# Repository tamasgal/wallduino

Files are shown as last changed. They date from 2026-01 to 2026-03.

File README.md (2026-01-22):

# WallDuino

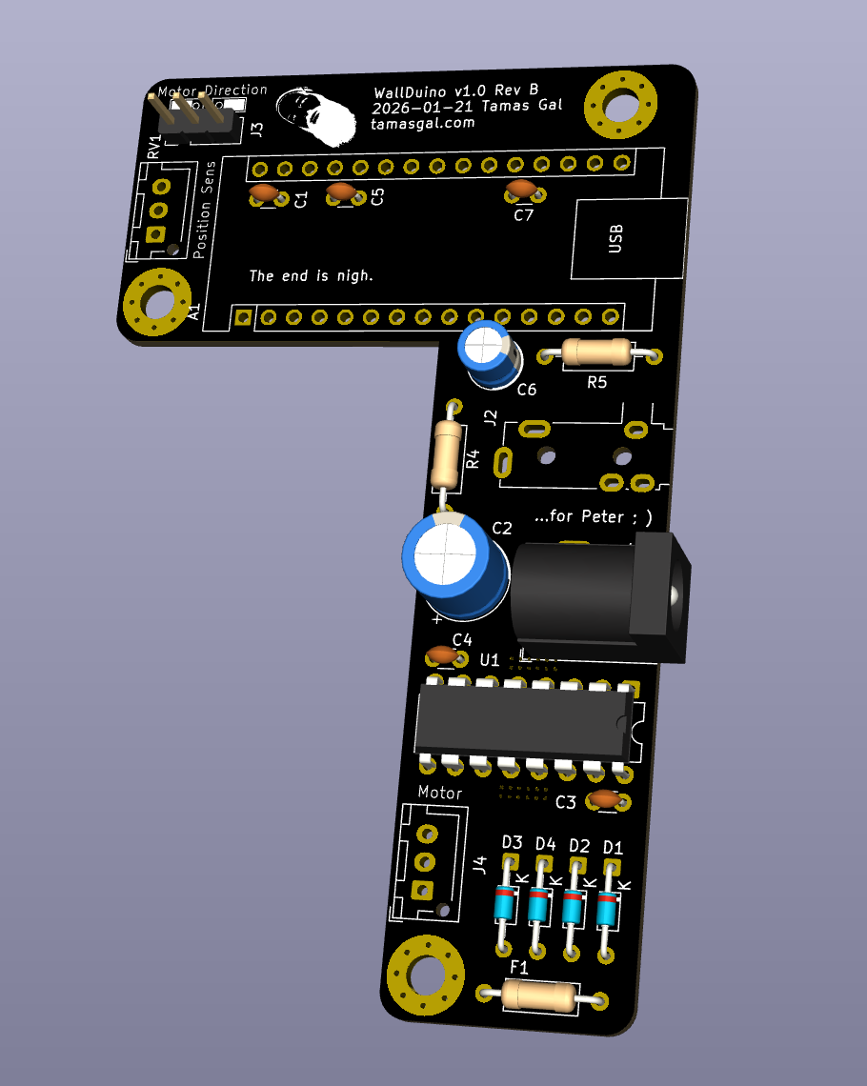
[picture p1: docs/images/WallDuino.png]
WallDuino


Drop-in replacement board for the WallWizard remote-controlled TV wall mount
including PCB, DIY veroboard (stripboard) layouts and an open source firmware
for Arduino compatible microcontrollers.

Manual: [`WallDuino_Manual.pdf`](https://github.com/tamasgal/wallduino/blob/main/docs/WallDuino_Manual.pdf)

## Firmware

Board: Arduino Nano compatible
Dependency: [Arduino-IRRemote v4.5](https://github.com/Arduino-IRremote/Arduino-IRremote)
Code: `firmware/WallDuino`

### Changelog

#### v1.1 - 2026-01-22

- Persistent presets after reboot
- Home button support to "go home"

#### v1.0 - 2026-01-09

Initial release

## PCB

### v1.0 (Rev A) 2026-01-08

First release.

### v1.0 (Rev B) 2026-01-21

- Heat sinking of the L293D improved significantly
- R1, R2 and R3 removed
- Added an additional capacitor to smooth out the position sensor signal from the potentiometer

## DIY Veroboard

The veroboard (stripboard) is Rev A and has a different Arduino pinout, so make sure
to adjust the firmware code.

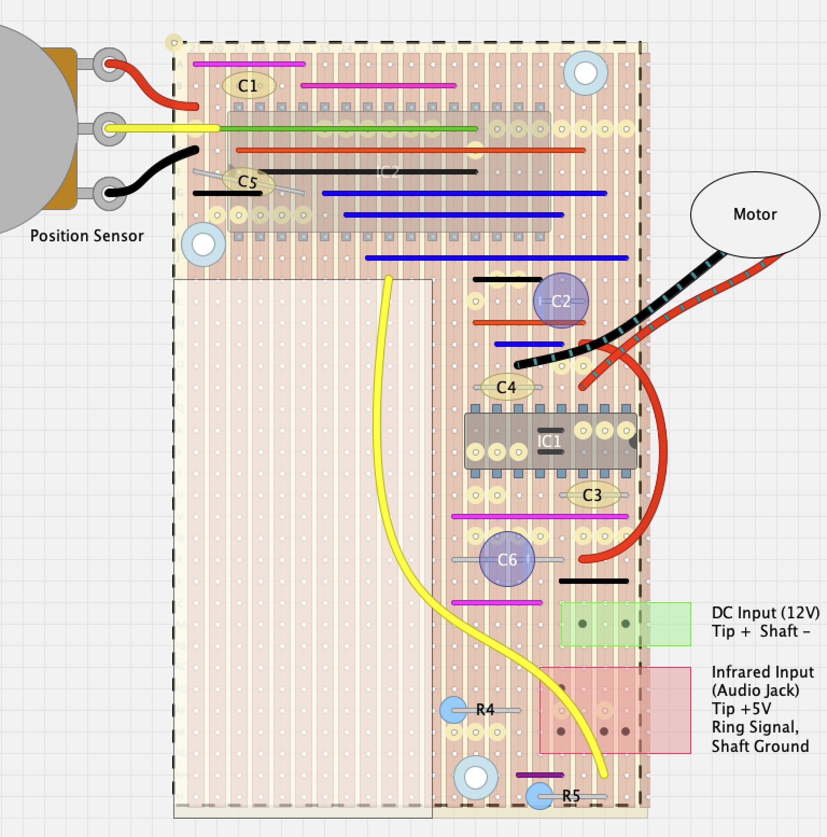
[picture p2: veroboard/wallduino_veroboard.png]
WallDuino


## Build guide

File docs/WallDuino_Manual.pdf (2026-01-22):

# WallDuino

## Open Source Ersatzboard für motorisierte WallWizard TV-Wandhalterungen

### Open-source replacement board for Motorized WallWizard TV Wall Mounts

### Tamas Gal - https://www.tamasgal.com

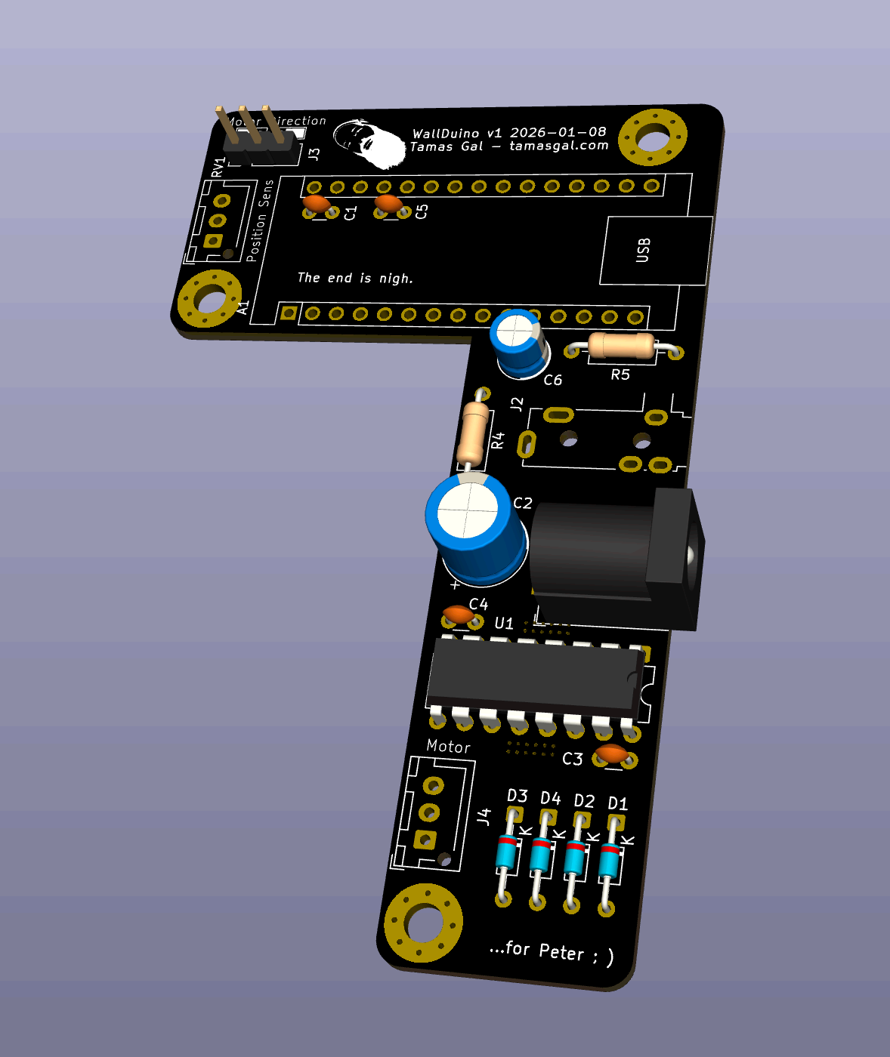
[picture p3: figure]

Bedienungsanleitung / User Manual

Custom DIY Mainboard Replacement

# Bedienungsanleitung

## Einleitung

Dieses Handbuch beschreibt die Verwendung des WallDuino, einer selbstgebauten DIY-Platine, die als Ersatz für die originale WallWizard-Hauptplatine (P/N: 417-S3-001-00 CLO SYSTEMS 2010.12.25) dient.

Der WallDuino ist vollständig kompatibel mit dem originalen Layout und der originalen Fernbedienung des WallWizard-Systems. Die Platine wurde entwickelt, um alle Funktionen der Originalplatine zu ersetzen und bietet zusätzlich die Möglichkeit zur Anpassung der Firmware.

Open Source Projekt: Der WallDuino ist ein Open-Source-Projekt. Die Firmware und alle Designdateien finden Sie im offiziellen Git-Repository: https://github.com/tamasgal/wallduino

## Übersicht

Der WallDuino steuert eine motorisierte TV-Wandhalterung, die es Ihnen ermöglicht, Ihren Fernseher horizontal nach links und rechts zu bewegen. Die Steuerung erfolgt bequem über die kompatible Fernbedienung.

## Fernbedienung

Die Fernbedienung verfügt über folgende Tasten:

Taste | Funktion
◄ Links | Bewegt die Halterung nach links
- Rechts | Bewegt die Halterung nach rechts
■ Stop | Stoppt die Bewegung sofort
Preset 1 | Positionsspeicher 1
Preset 2 | Positionsspeicher 2

## Bedienung

Grundlegende Bewegung
Links/Rechts bewegen:
- Drücken Sie die Taste ◄ (Links) oder ► (Rechts)
- Die Halterung bewegt sich in die gewählte Richtung

- Die Bewegung stoppt automatisch bei Erreichen der Endposition Bewegung stoppen:
- Drücken Sie die ■ (Stop)-Taste, um die Bewegung jederzeit zu unterbrechen

Preset-Positionen
Die Preset-Tasten ermöglichen es Ihnen, zwei Lieblingspositionen zu speichern und schnell anzufahren.
Position anfahren:
- Drücken Sie einmal auf Preset 1 oder Preset 2
- Die Halterung fährt automatisch zur gespeicherten Position
Position speichern:
- Bewegen Sie die Halterung zur gewünschten Position
- Drücken Sie dreimal schnell hintereinander auf Preset 1 oder Preset 2
- Die aktuelle Position ist nun gespeichert

Hinweis: Die Preset-Positionen bleiben auch nach dem Ausschalten gespeichert.

## Sicherheitshinweise

- Achten Sie darauf, dass sich keine Gegenstände oder Personen im Bewegungsbereich befinden
- Verwenden Sie die Stop-Taste bei unerwarteten Hindernissen
- Prüfen Sie regelmäßig die sichere Montage der Halterung
- Bei Fehlfunktionen trennen Sie das Gerät vom Strom und kontaktieren Sie den Kundendienst

## Firmware-Anpassung

Ein besonderer Vorteil des WallDuino ist die Möglichkeit, die Firmware nach eigenen Wünschen anzupassen. Dies ermöglicht es Ihnen:
Zusätzliche Fernbedienungsbefehle hinzufügen:
- Ungenutzte Tasten bestehender TV-Fernbedienungen verwenden
- Beliebige andere Fernbedienungen einlernen
- Eigene Befehle und Funktionen programmieren Anpassungsmöglichkeiten:
- IR-Codes neuer Fernbedienungen hinzufügen
- Bewegungsgeschwindigkeit anpassen
- Zusätzliche Preset-Positionen definieren

- Spezielle Bewegungsabläufe programmieren

Die vollständige Firmware sowie Anleitungen zur Anpassung finden Sie im offiziellen Repository:
https://github.com/tamasgal/wallduino

# User Manual

## Introduction

This manual describes the use of the WallDuino, a custom DIY board that serves as a replacement for the original WallWizard mainboard (P/N: 417-S3-001-00 CLO SYSTEMS 2010.12.25).

The WallDuino is fully compatible with the original layout and the original remote control of the WallWizard system. The board was designed to replace all functions of the original board and additionally offers the possibility to customize the firmware.

Open Source Project: The WallDuino is an open source project. The firmware and all design files can be found in the official Git repository: https://github.com/tamasgal/wallduino

## Overview

The WallDuino controls a motorized TV wall mount that allows you to move your television horizontally to the left and right. Control is conveniently managed via the compatible remote control.

## Remote Control

The remote control features the following buttons:

Button | Function
◄ Left | Moves the mount to the left
- Right | Moves the mount to the right
■ Stop | Stops the movement immediately
Preset 1 | Position memory 1
Preset 2 | Position memory 2

## Operation

Basic Movement
Moving Left/Right:
- Press the ◄ (Left) or ► (Right) button
- The mount will move in the selected direction

- Movement stops automatically when reaching the end position Stopping Movement:
- Press the ■ (Stop) button to interrupt movement at any time

Preset Positions
The preset buttons allow you to save two favorite positions and navigate to them quickly.
Navigate to Position:
- Press Preset 1 or Preset 2 once
- The mount will automatically move to the saved position Save Position:
- Move the mount to the desired position
- Press Preset 1 or Preset 2 three times quickly in succession
- The current position is now saved

Note: Preset positions remain saved even after powering off.

## Safety Instructions

- Ensure no objects or persons are in the movement range
- Use the Stop button if unexpected obstacles appear
- Regularly check the secure mounting of the bracket
- In case of malfunction, disconnect the device from power and contact customer service

## Firmware Customization

A special advantage of the WallDuino is the ability to customize the firmware according to your own preferences. This allows you to:
Add Additional Remote Commands:
- Use unused buttons from existing TV remotes
- Learn any other remote controls
- Program custom commands and functions Customization Options:
- Add IR codes from new remote controls
- Adjust movement speed
- Define additional preset positions
- Program special movement sequences

The complete firmware and instructions for customization can be found in the official repository:
https://github.com/tamasgal/wallduino

# Anhang / Appendix

## PCB-Dokumentation / PCB Documentation

Die folgenden Seiten enthalten detaillierte technische Zeichnungen und Schaltpläne der WallDuino-Platine.

The following pages contain detailed technical drawings and schematics of the WallDuino board.

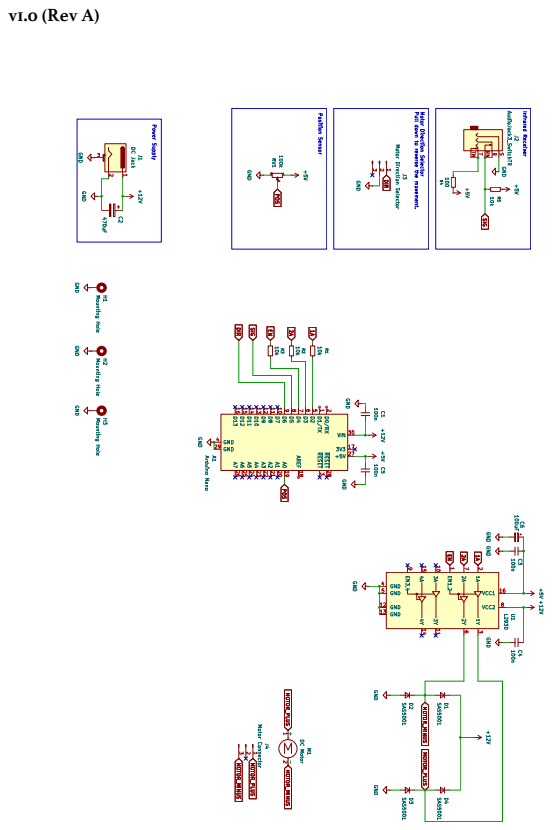
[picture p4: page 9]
v1.0 (Rev A)

## Vorderseite mit Beschriftung / Front Copper with Silkscreen

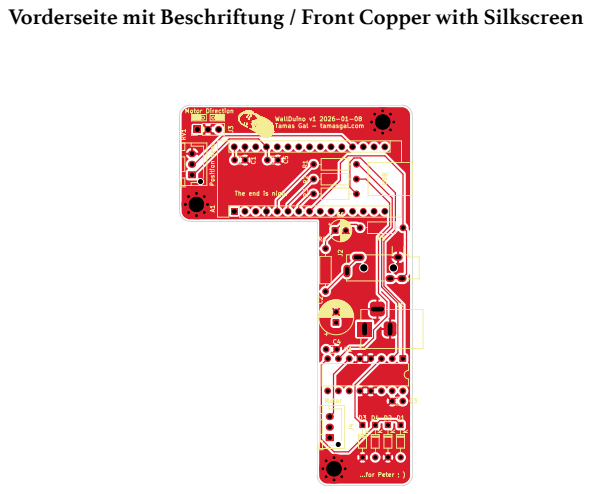
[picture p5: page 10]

## Vorderseite ohne Beschriftung / Front Copper without Silkscreen

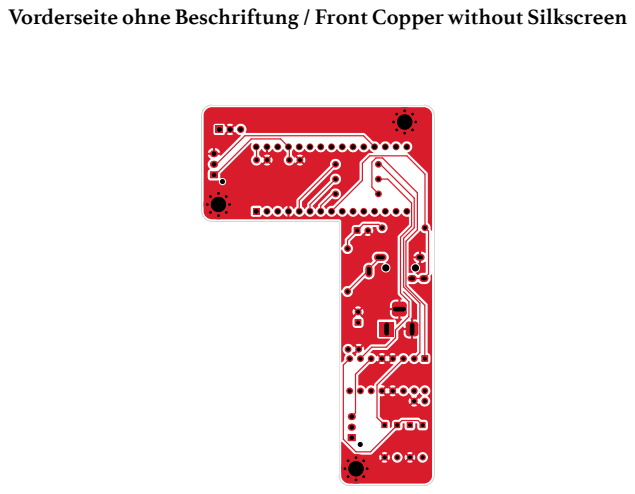
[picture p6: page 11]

## Rückseite mit Beschriftung / Back Copper with Silkscreen

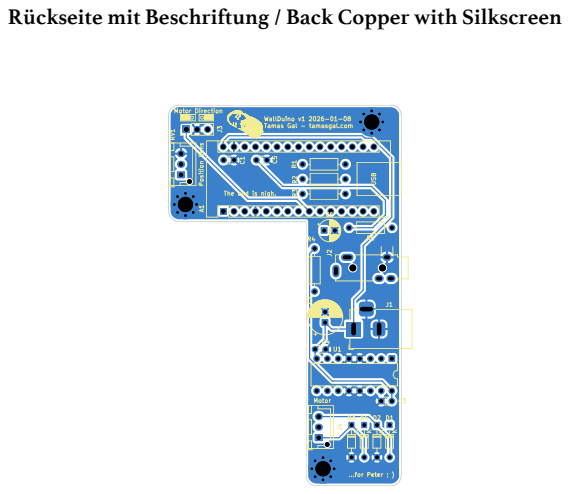
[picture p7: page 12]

## Rückseite ohne Beschriftung / Back Copper without Silkscreen

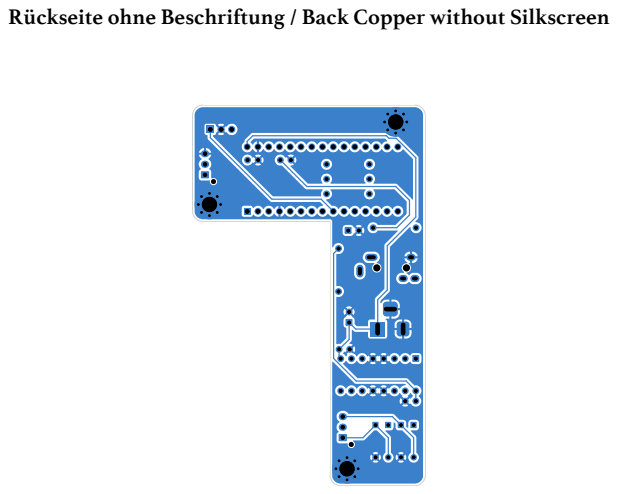
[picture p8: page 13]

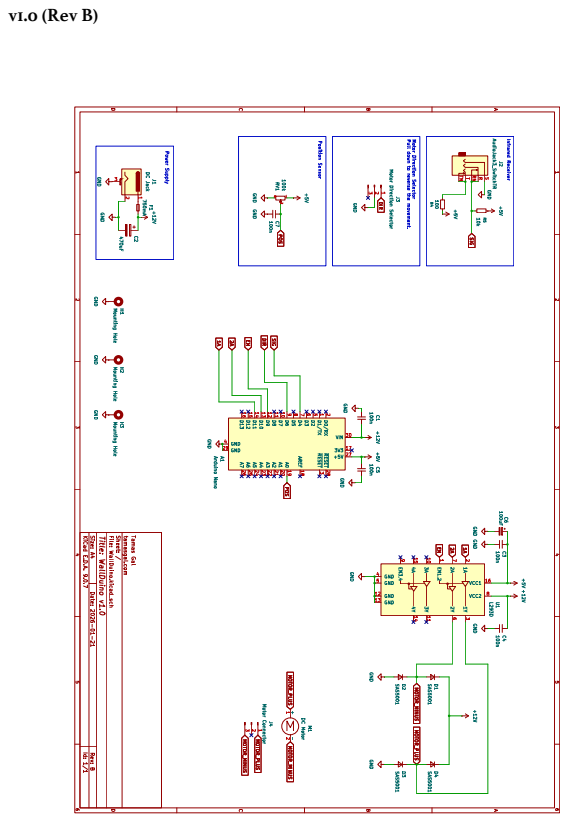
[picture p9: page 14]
v1.0 (Rev B)

## Vorderseite mit Beschriftung / Front Copper with Silkscreen

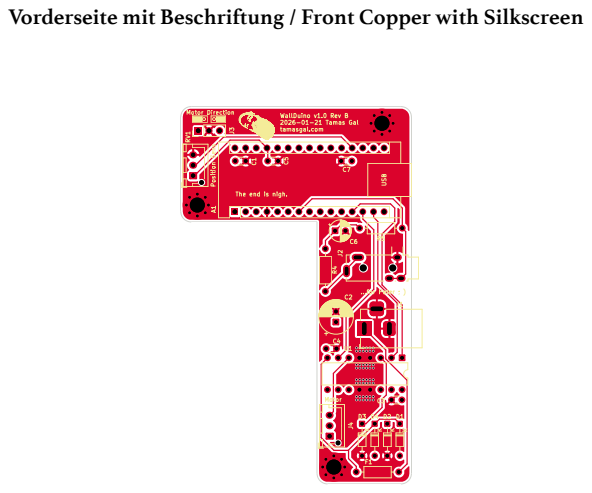
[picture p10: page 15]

## Vorderseite ohne Beschriftung / Front Copper without Silkscreen

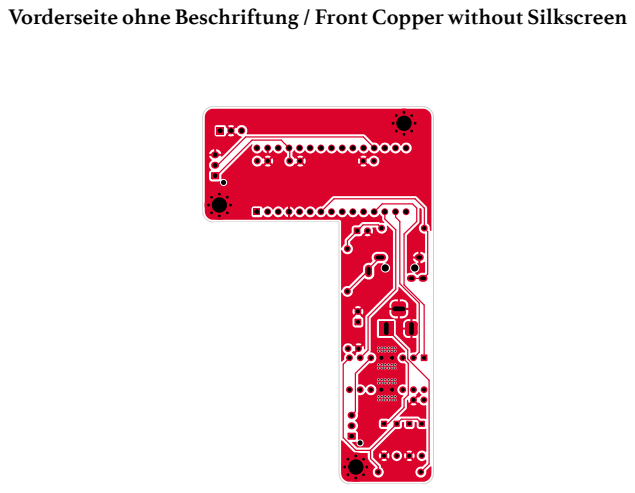
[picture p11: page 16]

## Rückseite mit Beschriftung / Back Copper with Silkscreen

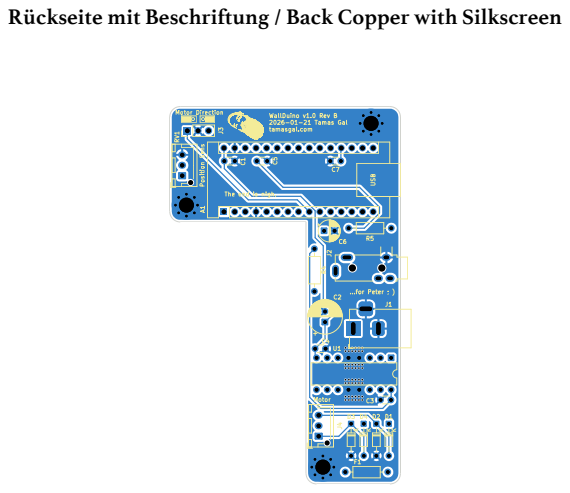
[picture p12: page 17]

## Rückseite ohne Beschriftung / Back Copper without Silkscreen

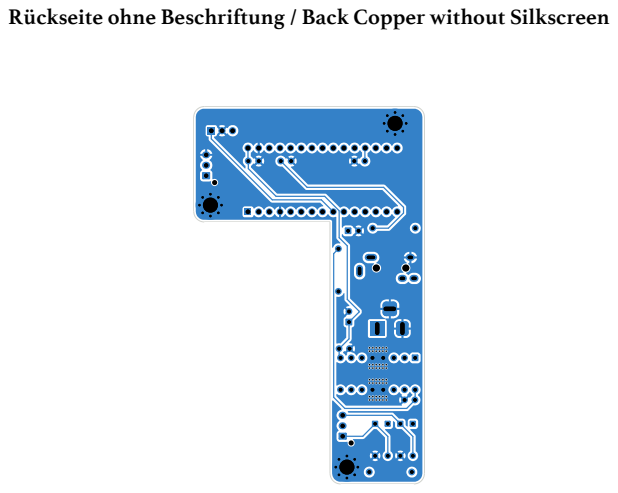
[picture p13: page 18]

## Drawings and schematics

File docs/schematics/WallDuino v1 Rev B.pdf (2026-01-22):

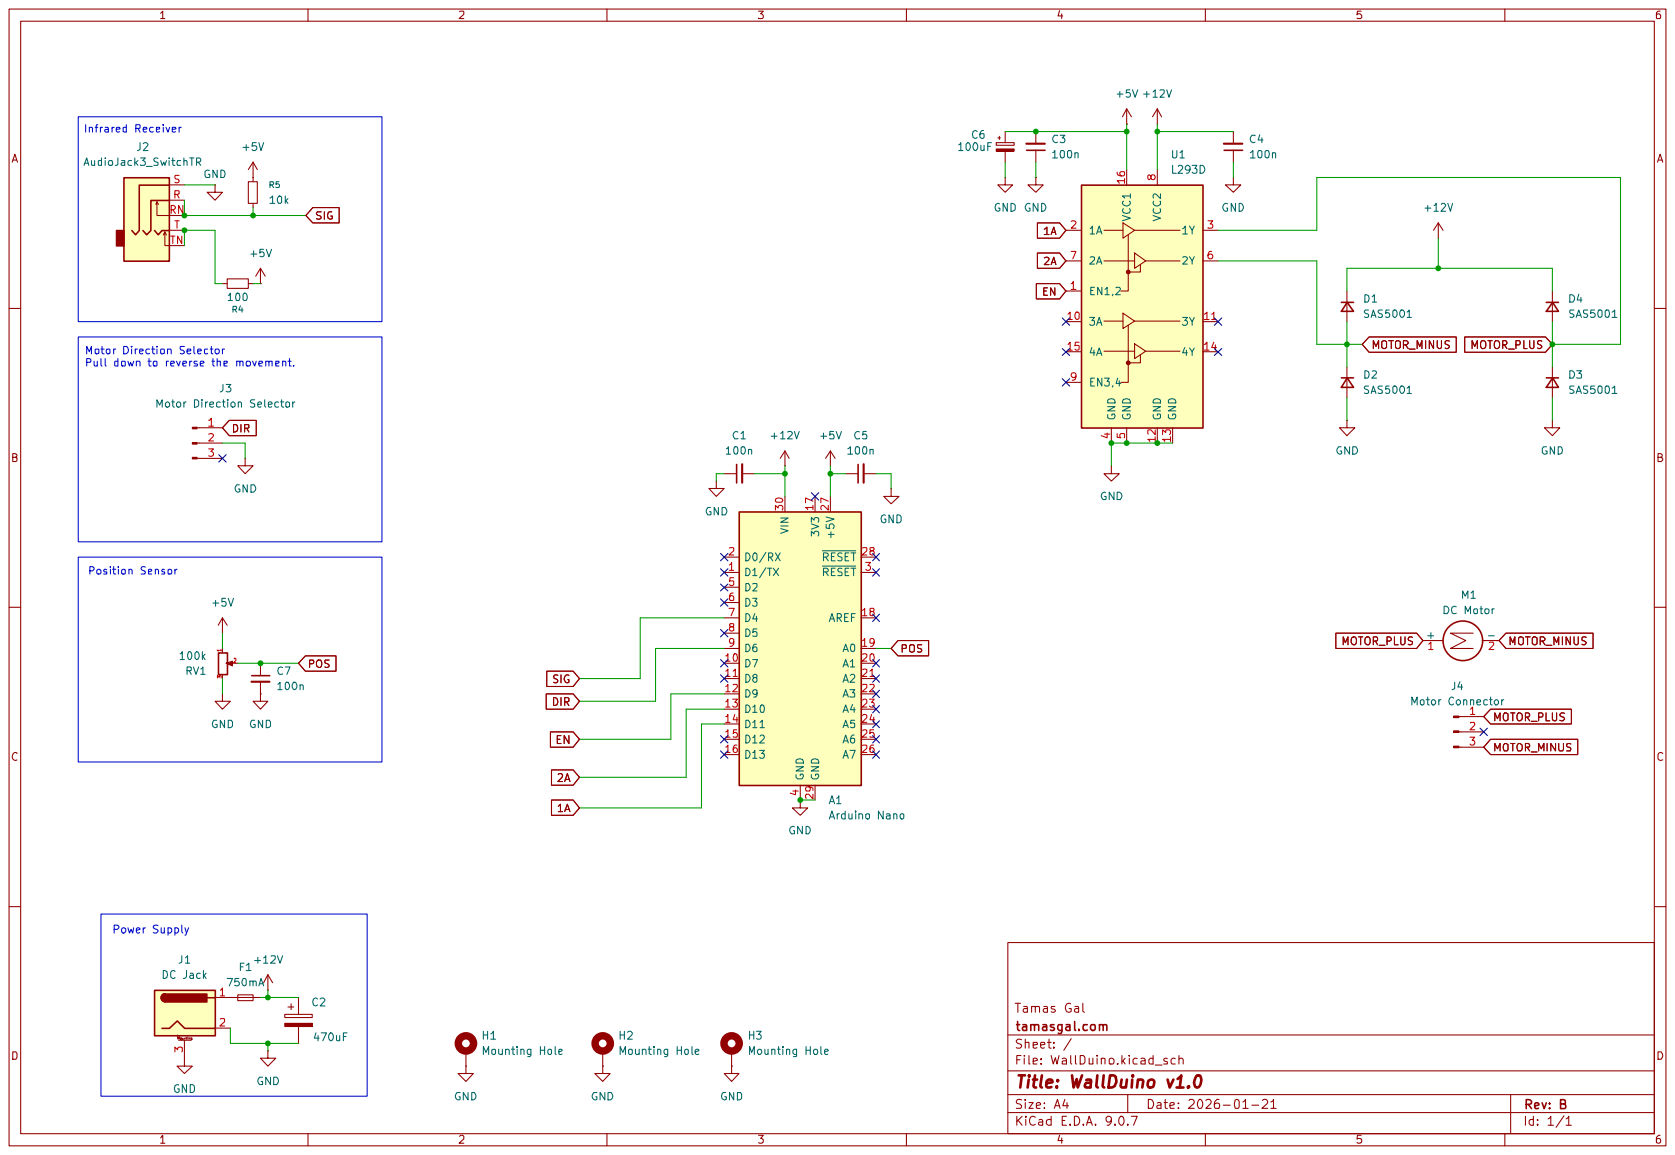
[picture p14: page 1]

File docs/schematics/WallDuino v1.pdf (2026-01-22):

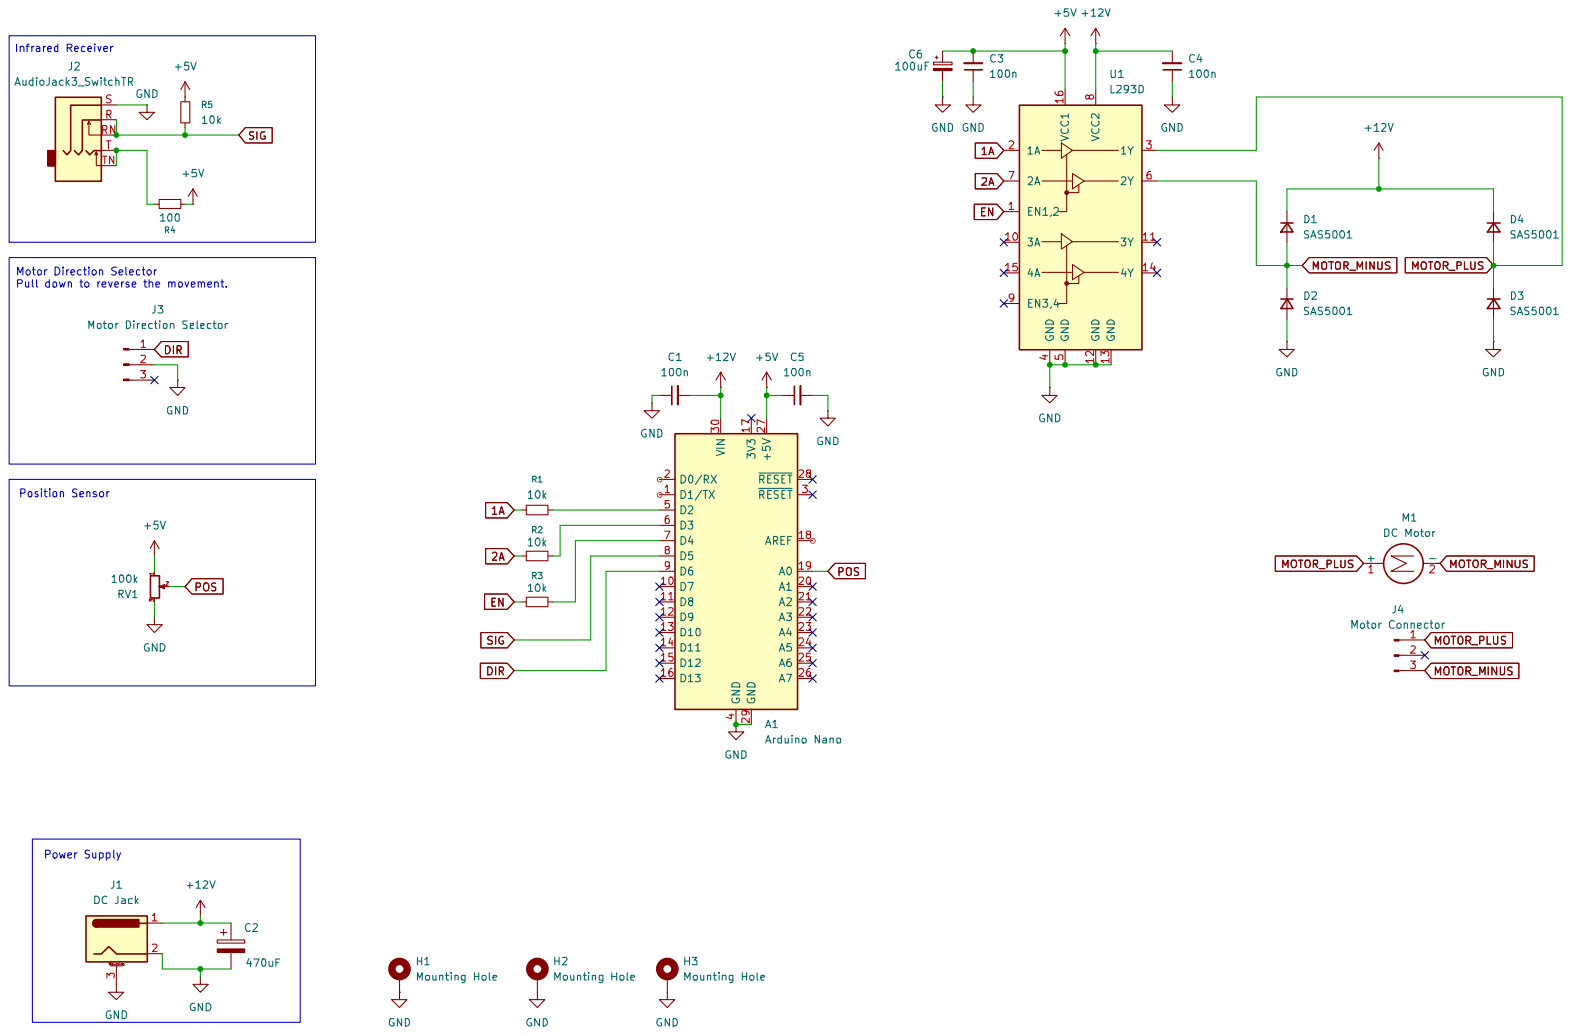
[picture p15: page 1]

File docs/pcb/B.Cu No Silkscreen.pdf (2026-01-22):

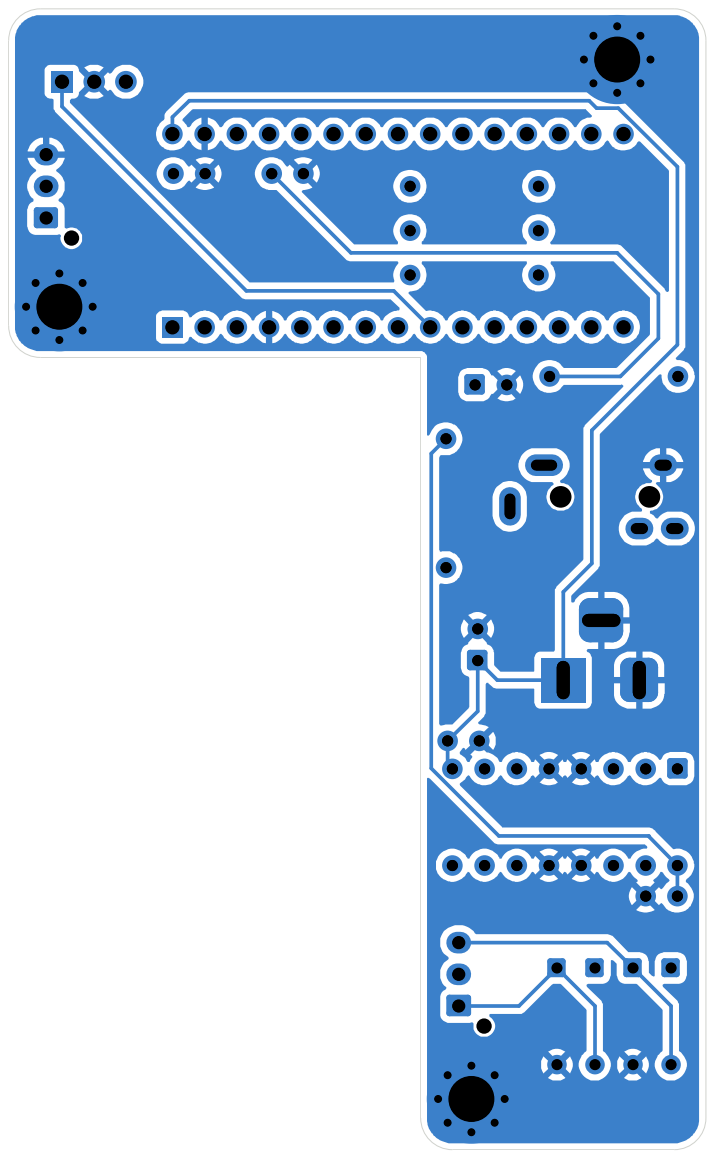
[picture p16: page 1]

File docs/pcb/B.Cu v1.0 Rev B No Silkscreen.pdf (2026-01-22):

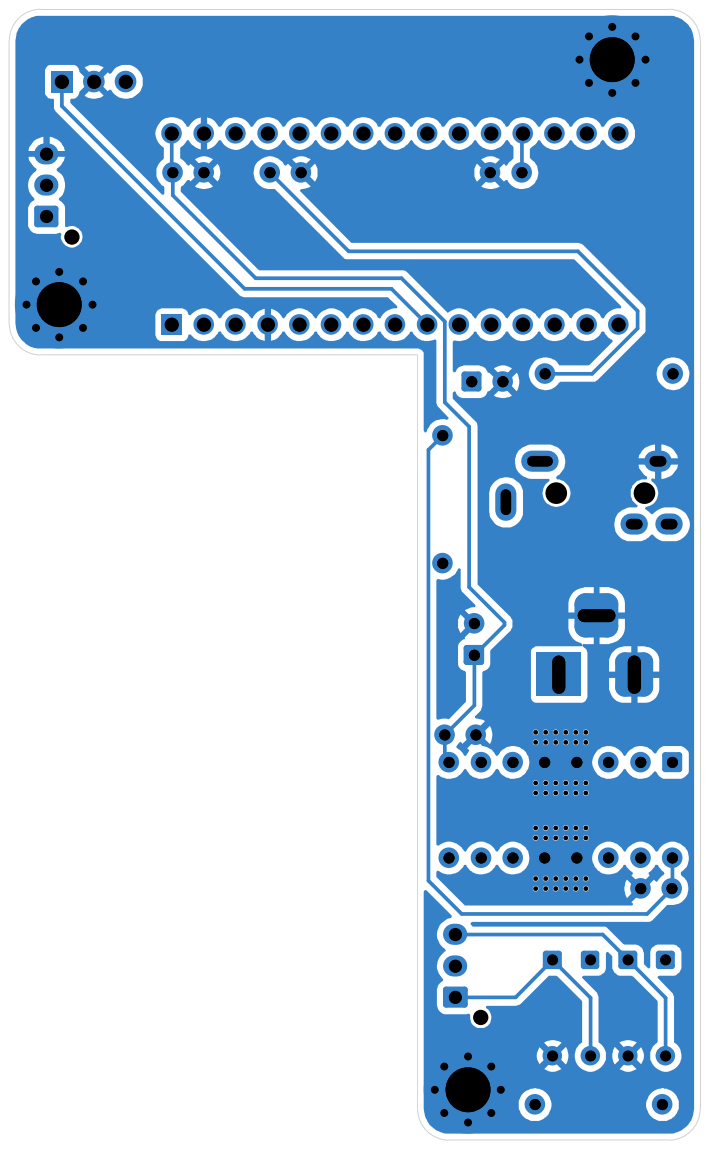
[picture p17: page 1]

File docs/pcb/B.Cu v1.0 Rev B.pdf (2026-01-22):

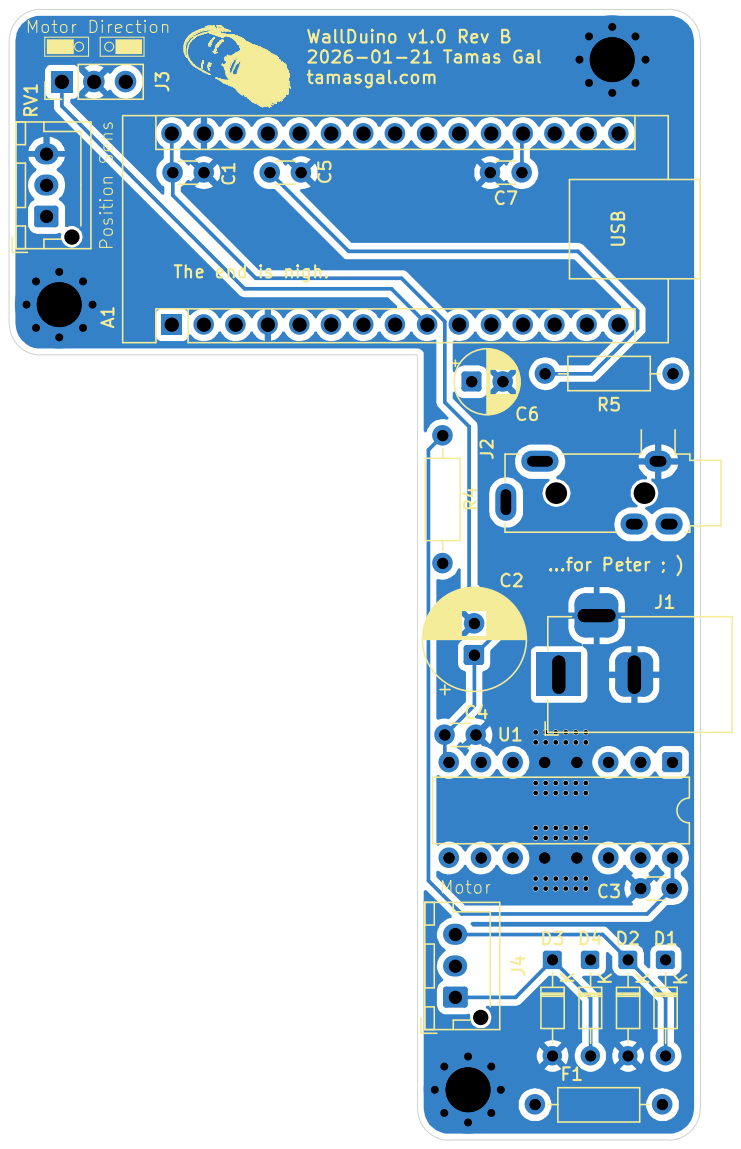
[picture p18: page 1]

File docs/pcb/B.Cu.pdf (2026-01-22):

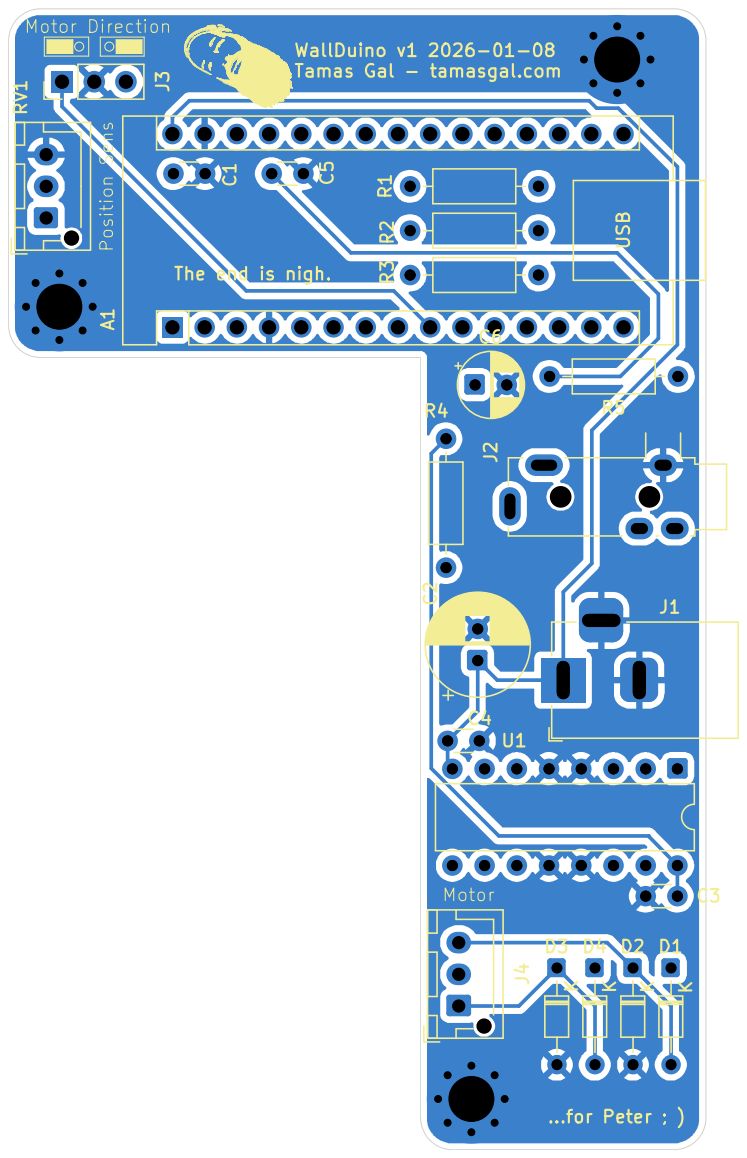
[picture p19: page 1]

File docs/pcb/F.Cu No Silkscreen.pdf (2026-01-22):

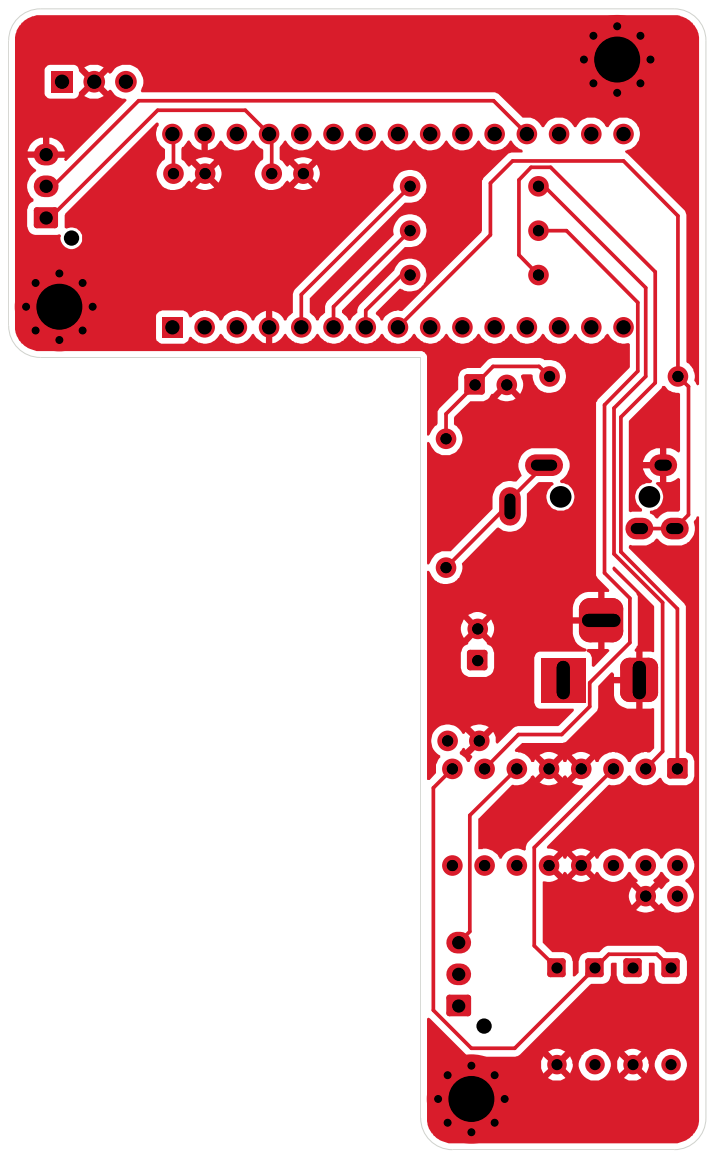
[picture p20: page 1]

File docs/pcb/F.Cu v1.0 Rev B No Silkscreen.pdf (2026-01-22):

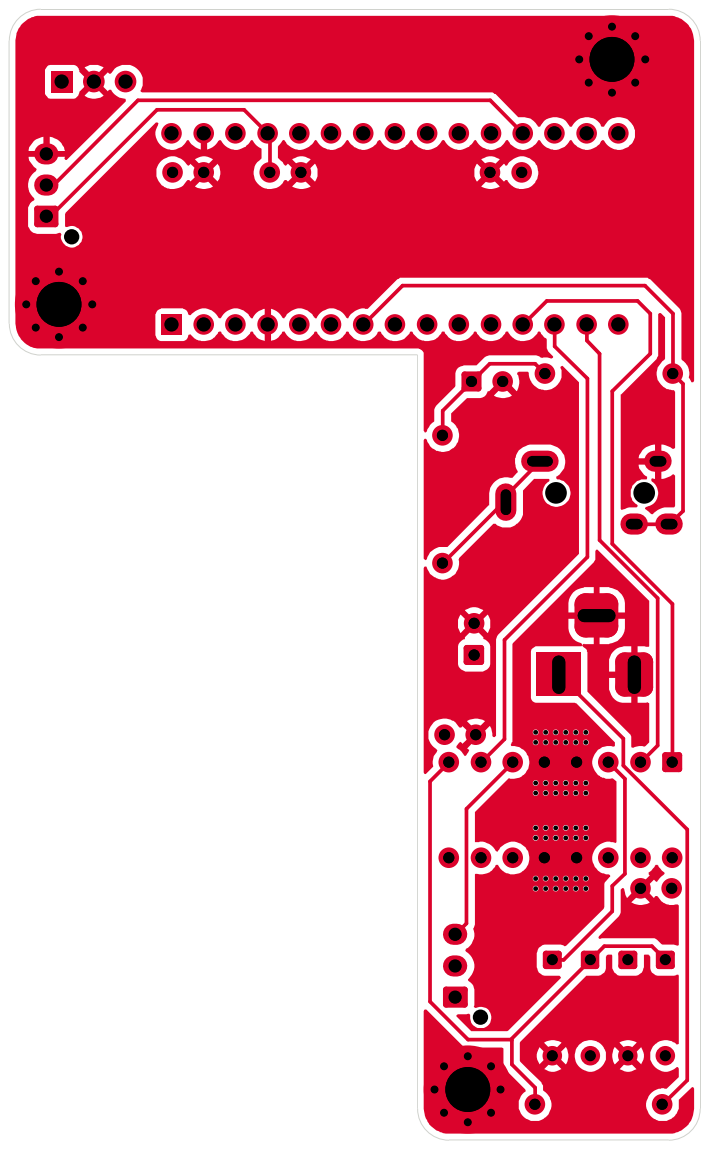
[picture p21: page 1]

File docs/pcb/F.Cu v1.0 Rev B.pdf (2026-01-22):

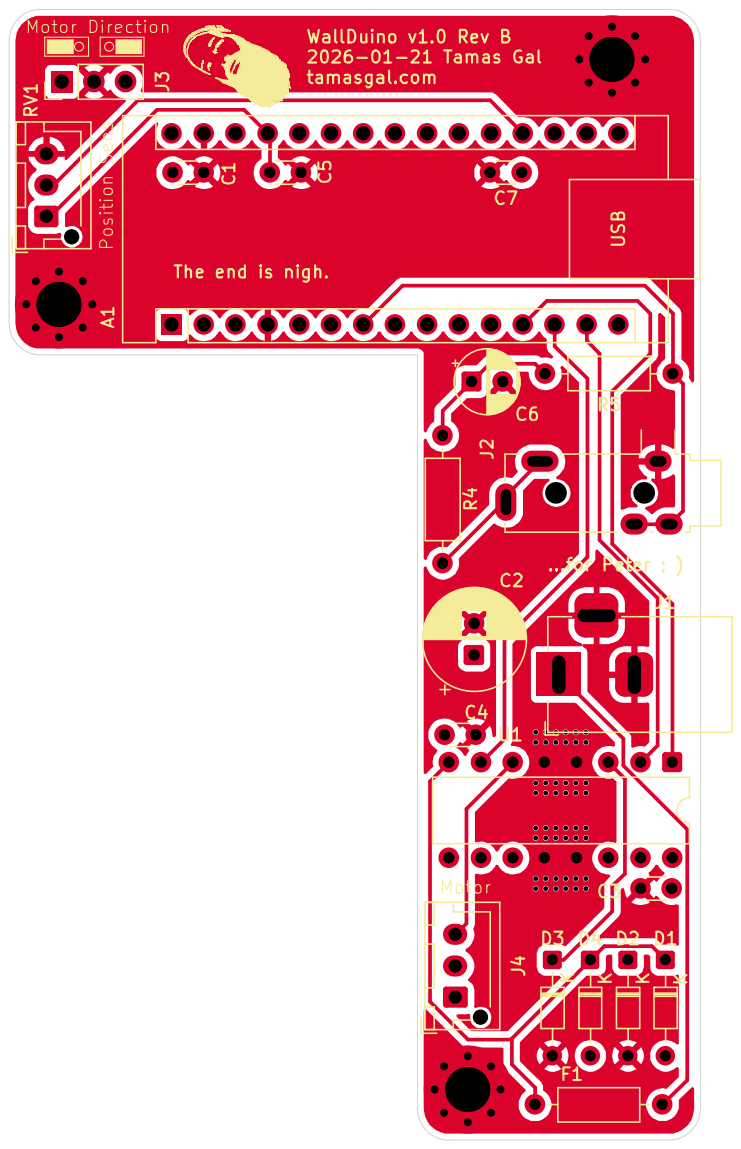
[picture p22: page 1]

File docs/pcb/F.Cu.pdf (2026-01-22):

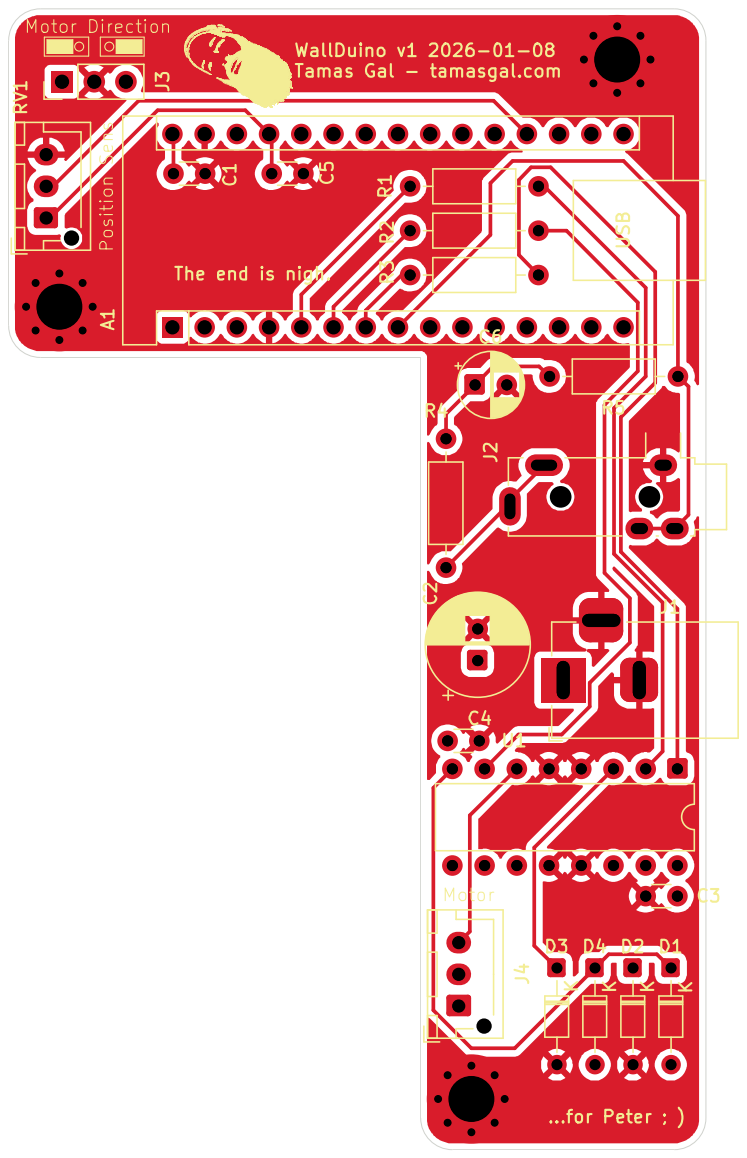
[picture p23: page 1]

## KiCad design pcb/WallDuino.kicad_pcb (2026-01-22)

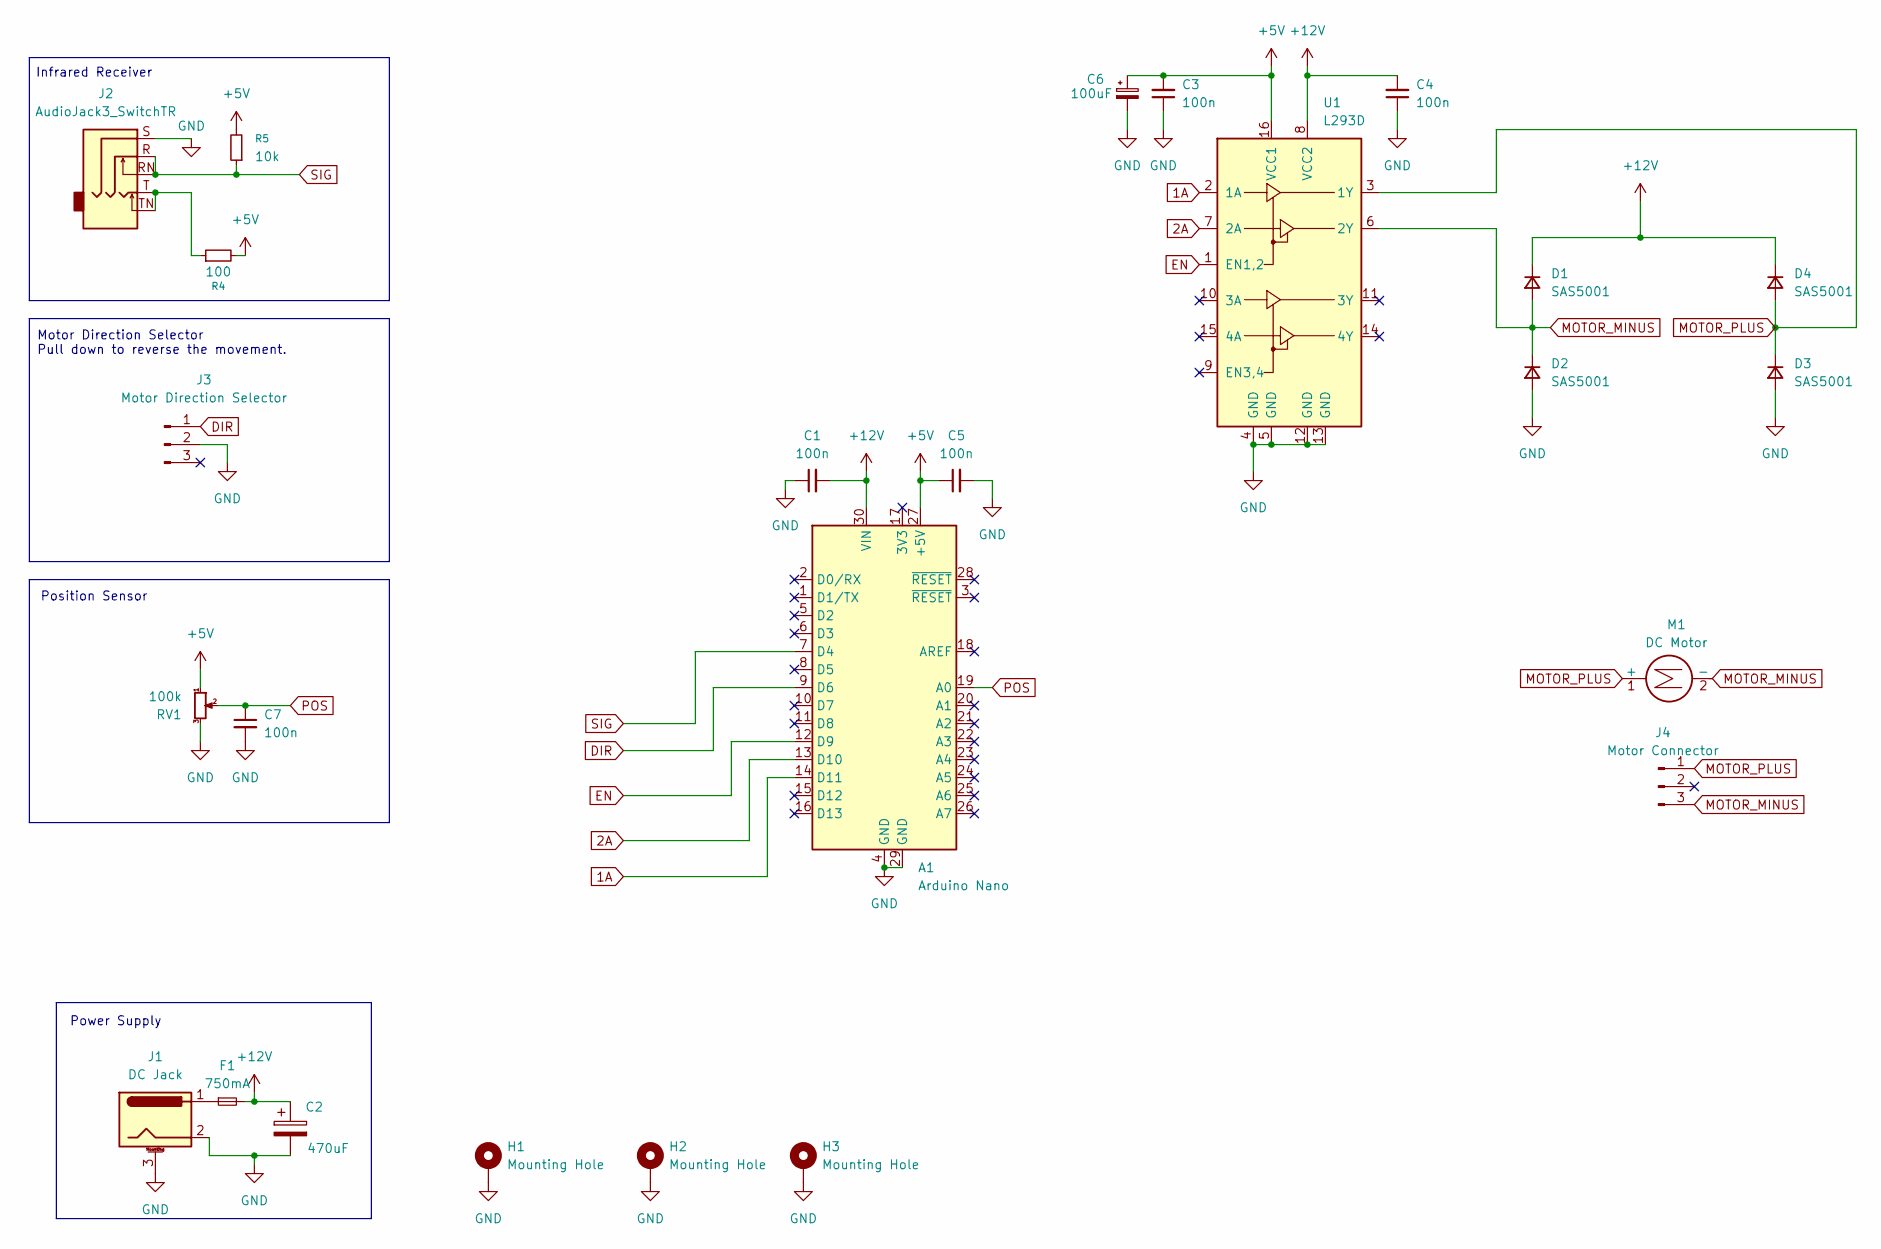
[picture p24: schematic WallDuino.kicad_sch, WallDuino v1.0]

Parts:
A1: Arduino Nano; Arduino_Nano
C1, C3, C4, C5, C7: 100n; C_Disc_D3.0mm_W1.6mm_P2.50mm
C2: 470uF; CP_Radial_D8.0mm_P2.50mm
C6: 100uF; CP_Radial_D5.0mm_P2.50mm
D1, D2, D3, D4: SAS5001; D_DO-34_SOD68_P7.62mm_Horizontal
F1: 750mA; R_Axial_DIN0207_L6.3mm_D2.5mm_P10.16mm_Horizontal
H1, H2, H3: Mounting Hole; MountingHole_3.5mm_Pad_Via
J1: DC Jack; BarrelJack_Horizontal
J2: AudioJack3_SwitchTR; Jack_3.5mm_CUI_SJ2-3593D-SMT_Horizontal
J3: Motor Direction Selector; PinHeader_1x03_P2.54mm_Vertical
J4: Motor Connector; JST_XH_B3B-XH-AM_1x03_P2.50mm_Vertical
M1: DC Motor
R4: 100; R_Axial_DIN0207_L6.3mm_D2.5mm_P10.16mm_Horizontal
R5: 10k; R_Axial_DIN0207_L6.3mm_D2.5mm_P10.16mm_Horizontal
RV1: 100k; JST_XH_B3B-XH-AM_1x03_P2.50mm_Vertical
U1: L293D; DIP-16_W7.62mm

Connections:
1A: A1.14 (D11), U1.2 (1A)
2A: A1.13 (D10), U1.7 (2A)
+5V: A1.27 (+5V), C3.2, C5.1, C6.1, R4.2, R5.2, RV1.1, U1.16 (VCC1)
+12V: A1.30 (VIN), C1.2, C2.1, C4.2, D1.1 (K), D4.1 (K), F1.2, U1.8 (VCC2)
DIR: A1.9 (D6), J3.1
EN: A1.12 (D9), U1.1 (EN1,2)
GND: A1.4 (GND), A1.29 (GND), C1.1, C2.2, C3.1, C4.1, C5.2, C6.2, C7.2, D2.2 (A), D3.2 (A), H1.1, H2.1, H3.1, J1.2, J1.3 (MountPin), J2.S, J3.2, RV1.3, U1.4 (GND), U1.5 (GND), U1.12 (GND), U1.13 (GND)
MOTOR_MINUS: D1.2 (A), D2.1 (K), J4.3, M1.2 (-), U1.6 (2Y)
MOTOR_PLUS: D3.1 (K), D4.2 (A), J4.1, M1.1 (+), U1.3 (1Y)
unnamed: F1.1, J1.1
unnamed: J2.T, J2.TN, R4.1
POS: A1.19 (A0), C7.1, RV1.2
SIG: A1.7 (D4), J2.R, J2.RN, R5.1

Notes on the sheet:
Infrared Receiver
Power Supply
Position Sensor
Motor Direction Selector Pull down to reverse the movement.

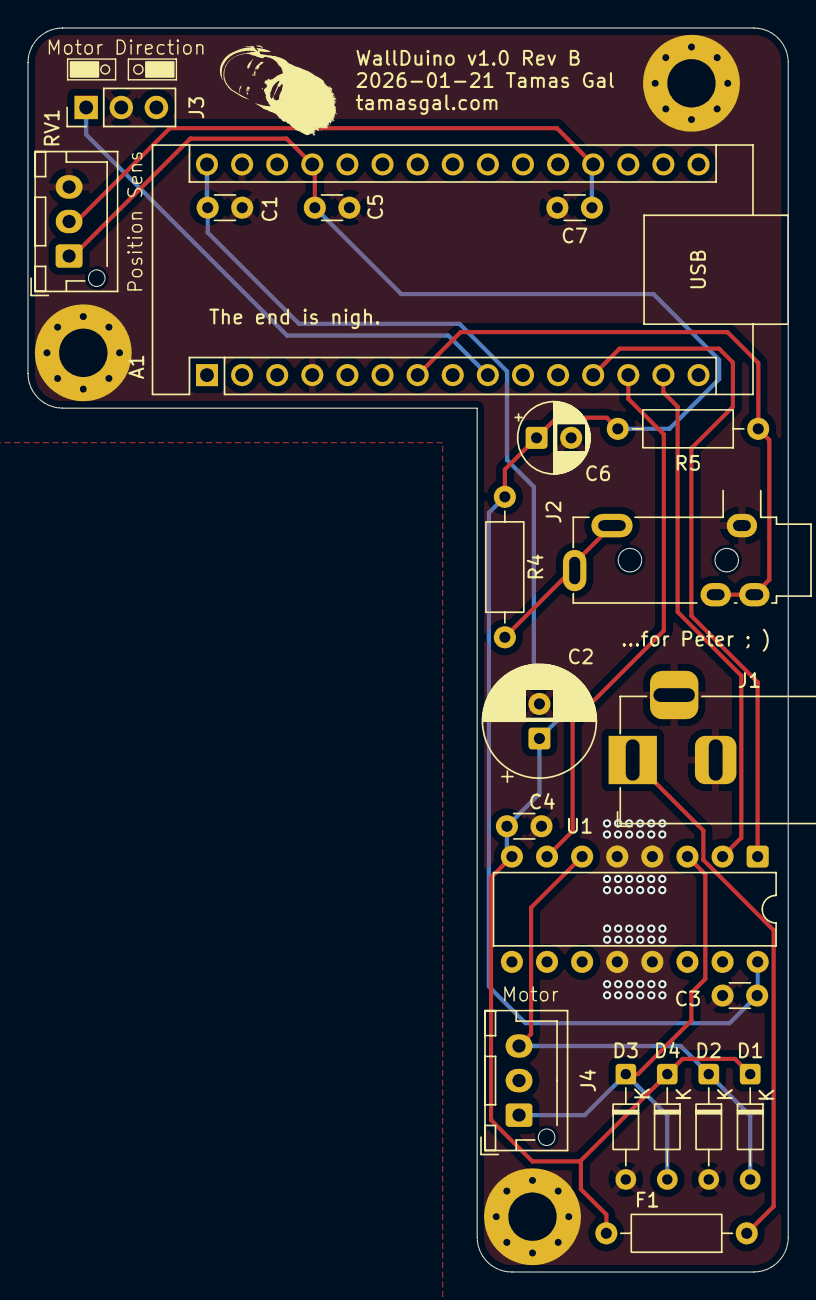
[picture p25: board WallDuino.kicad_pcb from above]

Board: 2 copper layers, 55.0 x 90.0 mm, 24 parts (0 on the bottom side), 13 nets.

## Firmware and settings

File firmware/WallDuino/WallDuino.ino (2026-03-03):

#include <IRremote.hpp>
#include <EEPROM.h>
#include <stdint.h>

#define WALLDUINO_VERSION 1.0

#define IR_RECEIVE_PIN 4  // 5
#define EN_PIN 9
#define A1_PIN 11  // 3
#define A2_PIN 10  //2
#define POSITION_PIN A0
#define MOTOR_DIRECTION_PIN 6
#define MIN_PRESSES_TO_SAVE_PRESET 7  // Logitech sends 3 with each press, so let's require 7 presses

#define EEPROM_PRESET1_ADDR 0
#define EEPROM_PRESET2_ADDR 4
#define EEPROM_MAGIC_ADDR 8
#define EEPROM_MAGIC_VALUE 0x42

#define SERIAL_DEBUG 0  // Set to 1 to enable, 0 to disable

#if SERIAL_DEBUG
#define DEBUG_BEGIN(baud) Serial.begin(baud)
#define DEBUG_PRINT(x) Serial.print(x)
#define DEBUG_PRINTLN(x) Serial.println(x)
#define DEBUG_PRINT2(x, y) Serial.print(x, y)
#else
#define DEBUG_BEGIN(baud)
#define DEBUG_PRINT(x)
#define DEBUG_PRINTLN(x)
#define DEBUG_PRINT2(x, y)
#endif

const float MIN_POSITION = 80.00f;                                           // [deg]
const float MAX_POSITION = 200.0f;                                           // [deg]
const float MAX_MOVEMENT = 10.0f;                                            // Maximum degrees per button press
const float HOME_POSITION = MAX_POSITION;                                    // Home position, when HOME is pressed
const float POSITION_TOLERANCE = 3.0f;                                       // [deg]
const unsigned long STOP_DELAY = 100;                                        // delay after motor stop [ms]
const unsigned long PRESET_TIMEOUT = 500;                                    // between consecutive clicks [ms]
const float DEFAULT_PRESET_POSITION = (MIN_POSITION + MAX_POSITION) / 2.0f;  // Default position for presets

struct RemoteSignature {
  decode_type_t protocol;
  uint16_t address;
  uint8_t command;
};

// IR Remote code signatures

const RemoteSignature LEFT_COMMANDS[] = {
  { NEC, 0x1, 0x4A },  // WallWizard
  //{SAMSUNG, 0x7, 0x6C}  // Samsung red
  { RC6, 0x0, 0x6D},    // Logitec RED
};

const RemoteSignature RIGHT_COMMANDS[] = {
  { NEC, 0x1, 0x4E },  // WallWizard
  { RC6, 0x0, 0x70},    // Logitec BLUE
};

const RemoteSignature STOP_COMMANDS[] = {
  { NEC, 0x1, 0x4F },  // WallWizard
  { RC6, 0x0, 0xA},    // Logitec EXIT
};

const RemoteSignature PRESET1_COMMANDS[] = {
  { NEC, 0x1, 0x13 },  // WallWizard
  { RC6, 0x0, 0x6F},    // Logitec YELLOW
};

const RemoteSignature PRESET2_COMMANDS[] = {
  { NEC, 0x1, 0x12 },  // WallWizard
};


const RemoteSignature HOME_COMMANDS[] = {
  { NEC, 0x1, 0xD },  // WallWizard
  { RC6, 0x0, 0x6E},    // Logitec GREEN
};

// Main logic

uint8_t preset1_counter = 0;
unsigned long preset1_timeout = 0;
float preset1_position = DEFAULT_PRESET_POSITION;
uint8_t preset2_counter = 0;
unsigned long preset2_timeout = 0;
float preset2_position = DEFAULT_PRESET_POSITION;

float targetPosition = -1;  // -1 means no active target

#define CHECK_COMMAND(arr) matchesSignature(arr, sizeof(arr) / sizeof(arr[0]), \
                                            IrReceiver.decodedIRData.protocol, \
                                            IrReceiver.decodedIRData.address, \
                                            IrReceiver.decodedIRData.command)
enum MotorState {
  STOPPED = 0,
  MOVING_LEFT = -1,
  MOVING_RIGHT = 1
};

MotorState motorState = STOPPED;

bool isMoving() {
  return motorState != STOPPED;
}

bool isMovingLeft() {
  return motorState == MOVING_LEFT;
}

bool isMovingRight() {
  return motorState == MOVING_RIGHT;
}

bool matchesSignature(const RemoteSignature* signatures, size_t count,
                      decode_type_t protocol, uint16_t address, uint8_t command) {
  for (size_t i = 0; i < count; i++) {
    if (signatures[i].protocol == protocol && signatures[i].address == address && signatures[i].command == command) {
      return true;
    }
  }
  return false;
}

bool leftKeyPressed() {
  return CHECK_COMMAND(LEFT_COMMANDS);
}

bool rightKeyPressed() {
  return CHECK_COMMAND(RIGHT_COMMANDS);
}

bool stopKeyPressed() {
  return CHECK_COMMAND(STOP_COMMANDS);
}

bool homeKeyPressed() {
  return CHECK_COMMAND(HOME_COMMANDS);
}

bool preset1KeyPressed() {
  return CHECK_COMMAND(PRESET1_COMMANDS);
}

bool preset2KeyPressed() {
  return CHECK_COMMAND(PRESET2_COMMANDS);
}


void writeFloatToEEPROM(int address, float value) {
  EEPROM.put(address, value);
}

float readFloatFromEEPROM(int address) {
  float value;
  EEPROM.get(address, value);
  return value;
}

void initializeEEPROM() {
  uint8_t magic = EEPROM.read(EEPROM_MAGIC_ADDR);
  if (magic != EEPROM_MAGIC_VALUE) {
    // EEPROM not initialized, write defaults
    Serial.println("Initializing EEPROM with default values...");
    writeFloatToEEPROM(EEPROM_PRESET1_ADDR, DEFAULT_PRESET_POSITION);
    writeFloatToEEPROM(EEPROM_PRESET2_ADDR, DEFAULT_PRESET_POSITION);
    EEPROM.write(EEPROM_MAGIC_ADDR, EEPROM_MAGIC_VALUE);
    preset1_position = DEFAULT_PRESET_POSITION;
    preset2_position = DEFAULT_PRESET_POSITION;
    Serial.print("Default preset positions set to: ");
    Serial.println(DEFAULT_PRESET_POSITION);
  } else {
    // EEPROM already initialized, read values
    Serial.println("Loading preset positions from EEPROM...");
    preset1_position = readFloatFromEEPROM(EEPROM_PRESET1_ADDR);
    preset2_position = readFloatFromEEPROM(EEPROM_PRESET2_ADDR);
    Serial.print("Preset 1 position: ");
    Serial.println(preset1_position);
    Serial.print("Preset 2 position: ");
    Serial.println(preset2_position);
  }
}

void savePreset1Position(float position) {
  preset1_position = position;
  writeFloatToEEPROM(EEPROM_PRESET1_ADDR, position);
  Serial.print("Preset 1 saved to EEPROM at position: ");
  Serial.println(preset1_position);
}

void savePreset2Position(float position) {
  preset2_position = position;
  writeFloatToEEPROM(EEPROM_PRESET2_ADDR, position);
  Serial.print("Preset 2 saved to EEPROM at position: ");
  Serial.println(preset2_position);
}

void setup() {
  Serial.begin(115200);
#if SERIAL_DEBUG
    delay(3000);  // give the serial monitor time to open and see the very first messages
#endif

  Serial.print("\nStarting WallDuino version ");
  Serial.println(WALLDUINO_VERSION);

  pinMode(EN_PIN, OUTPUT);
  pinMode(A1_PIN, OUTPUT);
  pinMode(A2_PIN, OUTPUT);
  pinMode(MOTOR_DIRECTION_PIN, INPUT_PULLUP);
  motorStop();
  unsetTarget();
  initializeEEPROM();

  IrReceiver.begin(IR_RECEIVE_PIN, ENABLE_LED_FEEDBACK);
}

int getMotorDirection() {
  return digitalRead(MOTOR_DIRECTION_PIN) == HIGH ? 1 : -1;
}


void motorLeft() {
  if (isMovingRight()) {
    DEBUG_PRINTLN("Motor is moving right, stopping first.");
    motorStop();
    Serial.println("Now moving left.");
  }
  motorState = MOVING_LEFT;
  digitalWrite(A1_PIN, HIGH);
  digitalWrite(A2_PIN, LOW);
  digitalWrite(EN_PIN, HIGH);
}

void motorRight() {
  if (isMovingLeft()) {
    DEBUG_PRINTLN("Motor is moving left, stopping first.");
    motorStop();
    Serial.println("Now moving right.");
  }
  motorState = MOVING_RIGHT;
  digitalWrite(A1_PIN, LOW);
  digitalWrite(A2_PIN, HIGH);
  digitalWrite(EN_PIN, HIGH);
}

void motorStop() {
  digitalWrite(EN_PIN, LOW);
  delay(STOP_DELAY);
  motorState = STOPPED;
  Serial.print("Motor stopped at ");
  float pos = readPosition();
  Serial.println(pos);
}

// Return the current position in degrees
float readPosition() {
  int raw = analogRead(POSITION_PIN);  // 0..1023
  return raw * (270.0f / 1023.0f);
}

void setTarget(float target) {
  targetPosition = clampPosition(target);
}

void unsetTarget() {
  targetPosition = -1;
}

bool targetIsSet() {
  return targetPosition >= 0;
}

void increaseTarget() {
  setTarget(readPosition() + MAX_MOVEMENT);
}

void decreaseTarget() {
  setTarget(readPosition() - MAX_MOVEMENT);
}

// Clamps the position to a safe range
float clampPosition(float position) {
  if (position < MIN_POSITION) {
    return MIN_POSITION;
  }
  if (position > MAX_POSITION) {
    return MAX_POSITION;
  }
  return position;
}

void printTarget() {
  Serial.print("Moving from ");
  Serial.print(readPosition());
  Serial.print(" to ");
  Serial.println(targetPosition);
}

void loop() {

  if (preset1_counter > 0 && preset1_timeout != 0 && millis() - preset1_timeout >= PRESET_TIMEOUT) {
    Serial.println("Preset 1 requested");
    setTarget(preset1_position);
    printTarget();
    preset1_counter = 0;
    preset1_timeout = 0;
  }
  if (preset2_counter > 0 && preset2_timeout != 0 && millis() - preset2_timeout >= PRESET_TIMEOUT) {
    Serial.println("Preset 2 requested");
    setTarget(preset2_position);
    printTarget();
    preset2_counter = 0;
    preset2_timeout = 0;
  }

  if (targetIsSet()) {
    float currentPosition = readPosition();
    // we allow an external jumper to change the actual direction of movement
    float deltaPosition = getMotorDirection() * (targetPosition - currentPosition);

    if (abs(deltaPosition) < POSITION_TOLERANCE) {
      motorStop();
      Serial.print("Target reached: ");
      Serial.print(targetPosition);
      Serial.print(" (deviation: ");
      Serial.print(deltaPosition);
      Serial.println(")");
      unsetTarget();
    } else {
      if (deltaPosition > 0) {
        motorRight();
      } else {
        motorLeft();
      }
    }
  }

  if (IrReceiver.decode()) {
#if SERIAL_DEBUG
    IrReceiver.printIRResultShort(&Serial);
#endif
    auto& data = IrReceiver.decodedIRData;

    if (leftKeyPressed()) {
      Serial.println("LEFT");
      decreaseTarget();
      printTarget();
    } else if (rightKeyPressed()) {
      Serial.println("RIGHT");
      increaseTarget();
      printTarget();
    } else if (stopKeyPressed()) {
      Serial.println("STOP");
      unsetTarget();
      motorStop();
    } else if (homeKeyPressed()) {
      Serial.println("STOP");
      setTarget(HOME_POSITION);
      Serial.print("Going home: ");
      Serial.println(HOME_POSITION);
    } else if (preset1KeyPressed()) {
      Serial.println("PRESET 1");
      if (millis() - preset1_timeout < PRESET_TIMEOUT && preset1_timeout != 0) {
        // Pressed again within timeout
        preset1_counter++;
        Serial.print("Preset 1 counter: ");
        Serial.println(preset1_counter);

        if (preset1_counter >= MIN_PRESSES_TO_SAVE_PRESET) {
          savePreset1Position(readPosition());
          preset1_counter = 0;  // Reset counter
          preset1_timeout = 0;  // Reset timeout
        } else {
          preset1_timeout = millis();  // Restart timeout
        }
      } else {
        // First press or timeout expired
        preset1_counter = 1;
        preset1_timeout = millis();
      }
    } else if (preset2KeyPressed()) {
      Serial.println("PRESET 2");
      if (millis() - preset2_timeout < PRESET_TIMEOUT && preset2_timeout != 0) {
        // Pressed again within timeout
        preset2_counter++;
        Serial.print("Preset 2 counter: ");
        Serial.println(preset2_counter);

        if (preset2_counter >= MIN_PRESSES_TO_SAVE_PRESET) {
          savePreset2Position(readPosition());
          preset2_counter = 0;  // Reset counter
          preset2_timeout = 0;  // Reset timeout
        } else {
          preset2_timeout = millis();  // Restart timeout
        }
      } else {
        // First press or timeout expired
        preset2_counter = 1;
        preset2_timeout = millis();
      }
    }

    IrReceiver.resume();
  }
}

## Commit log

2026-01-15 Add KiCAD project
    [WallDuino.kicad_pcb, WallDuino.kicad_sch]
2026-01-22 Update PCB and Schematics to v1.0 Rev B
    [WallDuino.kicad_pcb, WallDuino.kicad_sch]
2026-01-22 Update PCB preview
